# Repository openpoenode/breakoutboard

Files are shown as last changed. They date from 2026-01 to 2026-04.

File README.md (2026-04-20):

# Overview

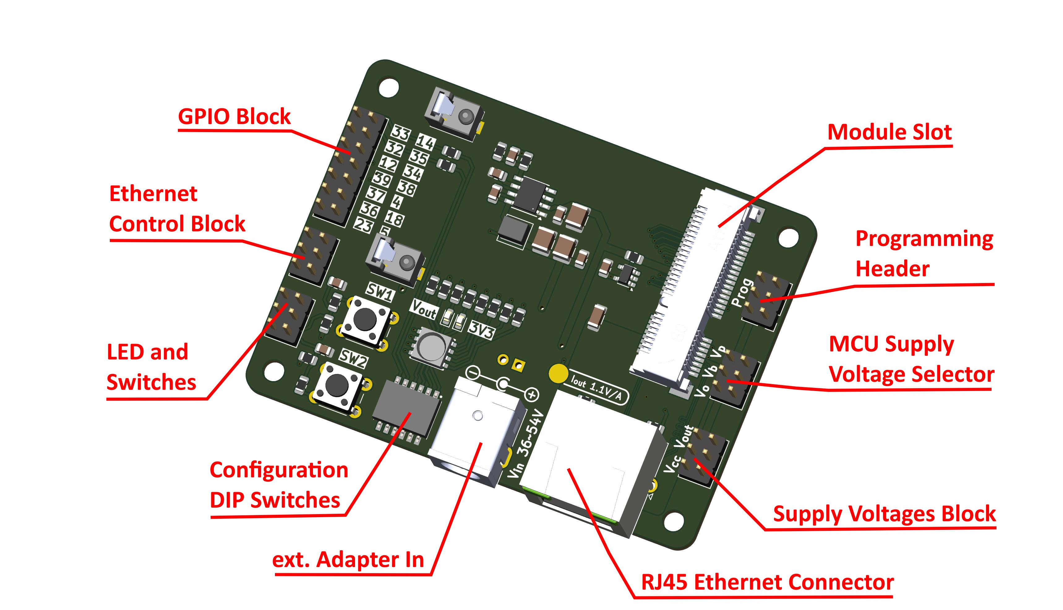
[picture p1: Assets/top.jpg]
BreakoutBoard


The **Breakout Board** carrier is designed to let developers explore the full feature set of the openPoeNode module before committing to a custom carrier design. It includes a range of practical features to simplify testing, evaluation, and firmware debugging.

# Features

The Breakout Board provides a single slot for an openPoeNode module with any supported output voltage. An onboard DC/DC converter is included to step down 5V module output to 3.3V for MCU supply.

## Supply Voltage Selector

The MCU section can be powered from one of three sources:

- Module V<sub>out</sub> directly (for 3.3V modules)
- V<sub>buck</sub> – output of the onboard DC/DC converter (V<sub>out</sub> → 3.3V)
- V<sub>prog</sub> – supplied by an external programmer or debugger

Select the desired source by placing a jumper cap on the corresponding pins.

Although the module includes overvoltage protection, avoid supplying 5V directly to the MCU section.

When powering the board via an external programmer, ensure it can provide sufficient current. Insufficient current may cause unstable behavior during programming (e.g., flash writes failing due to brownouts). If this occurs, use an external power adapter and select V<sub>buck</sub> as the supply source.

## Programming Header

Connector for an external programmer or debugger. The pinout matches the ESP-Prog board from Espressif.

## GPIO Block

All module GPIOs are broken out to this header for general-purpose use. Pin numbering follows the ESP32-D0WD-V3 datasheet.

## Ethernet Control Block

Three GPIOs are required to control the Ethernet interface (**GPIO2 / GPIO13 / GPIO15**). These are routed next to the corresponding **MDC / MDIO / Enable** pins.

- For normal operation, place jumper caps across each row to bridge the signals.
- For testing alternative pin assignments, the signals can be rerouted to other GPIOs using jumper wires.

## LED and Switches

The Breakout Board includes two tactile switches and one RGBW LED for quick testing.

### Switches

- Integrated pull-ups and hardware debouncing
- Output is pulled low when pressed

### LED

- Each channel’s anode is connected to 3.3V via a current-limiting resistor
- Cathodes are exposed on the header and can be driven by open-collector GPIOs

## Configuration DIP Switches

A 6-position DIP switch enables convenient hardware configuration during development:

- **I²C pull-ups (GPIO32 / GPIO33)**
  - 2.2 kΩ pull-ups for easy interfacing with I²C devices
  - Enable with Switch 1 & 2

- **Power load resistors**
  - 100 Ω and 56 Ω resistors from V<sub>out</sub> to GND
  - Useful when very low power consumption causes PoE instability (minimum draw > 0.44 W)
  - Helps prevent PoE power cycling (“hiccup” behavior)
  - Enable individually with Switch 3 & 4

- **Power indicators**
  - LEDs for V<sub>out</sub> and 3.3V rails
  - Enable/disable with Switch 5 & 6 (useful for precise power measurements)

## External Power Adapter

If PoE is unavailable or needs to be overridden, the board can be powered using an external 36–54V DC source.

- Connector: 5.5 × 2.1 mm barrel jack
- Polarity: center positive

## Supply Voltage Block

Provides power outputs for external devices (e.g., sensors):

- V<sub>out</sub> (1x)
- 3.3V (2x)
- Digital GND (3x)

Ensure total consumption remains within the DC/DC converter limits:
- 5V module: up to 1.4A
- 3.3V module: up to 2.1A

## PoE Voltage Block

For advanced use cases, raw PoE input voltage is available for external DC/DC converters.

⚠️ This connector is not populated by default and should be used with caution.

## Supply Current Monitoring

An onboard current monitor IC helps track power consumption and stay within PoE and DC/DC converter limits (0.44W < P < 7W).

- Measures I<sub>out</sub> via a 22 mΩ shunt resistor
- Measure voltage at the test pad (relative to digital ground)
- Current (A) = measured voltage / 1.1

# Physical

- Dimensions: 74 × 55 mm
- PCB: 4-layer FR4, 1.60 mm thickness

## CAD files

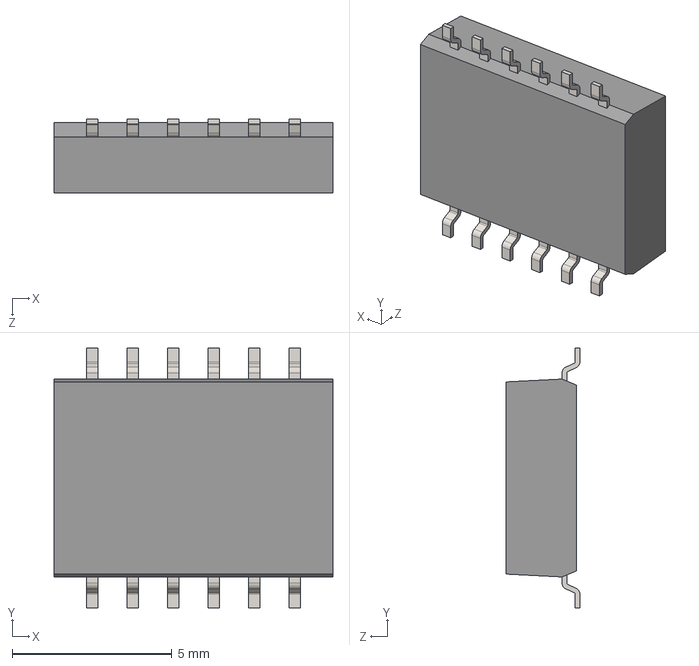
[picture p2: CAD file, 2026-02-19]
3D/GDH06S04.stp
8.74 x 8.13 x 2.31 mm

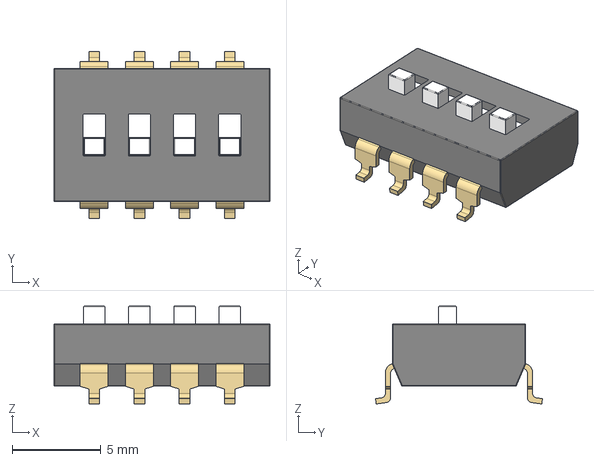
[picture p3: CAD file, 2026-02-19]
3D/ADE04S04.stp
12.1 x 9.38 x 5.50 mm

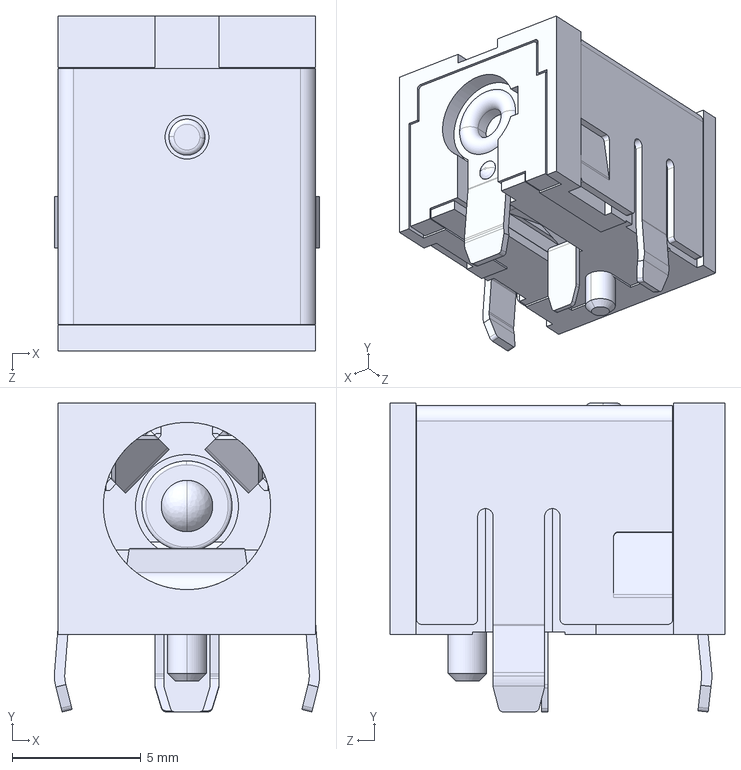
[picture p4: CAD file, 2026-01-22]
3D/PJ-063AH.stp
10.3 x 12.0 x 13.0 mm

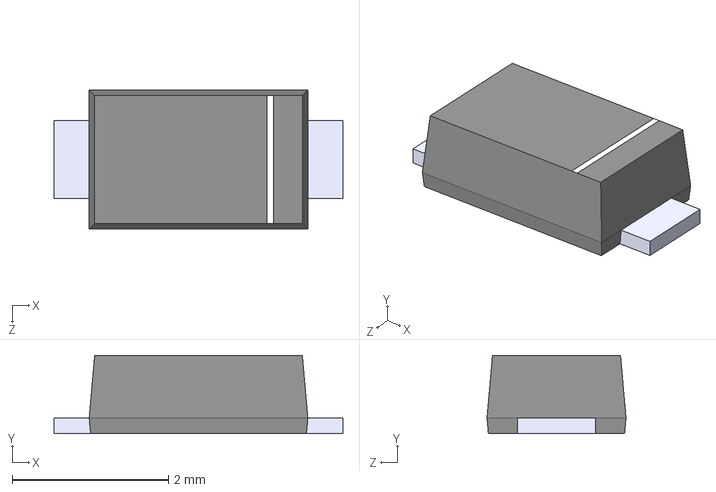
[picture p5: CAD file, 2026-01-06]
3D/AL5809-20P1-7.step
3.70 x 1.00 x 1.78 mm

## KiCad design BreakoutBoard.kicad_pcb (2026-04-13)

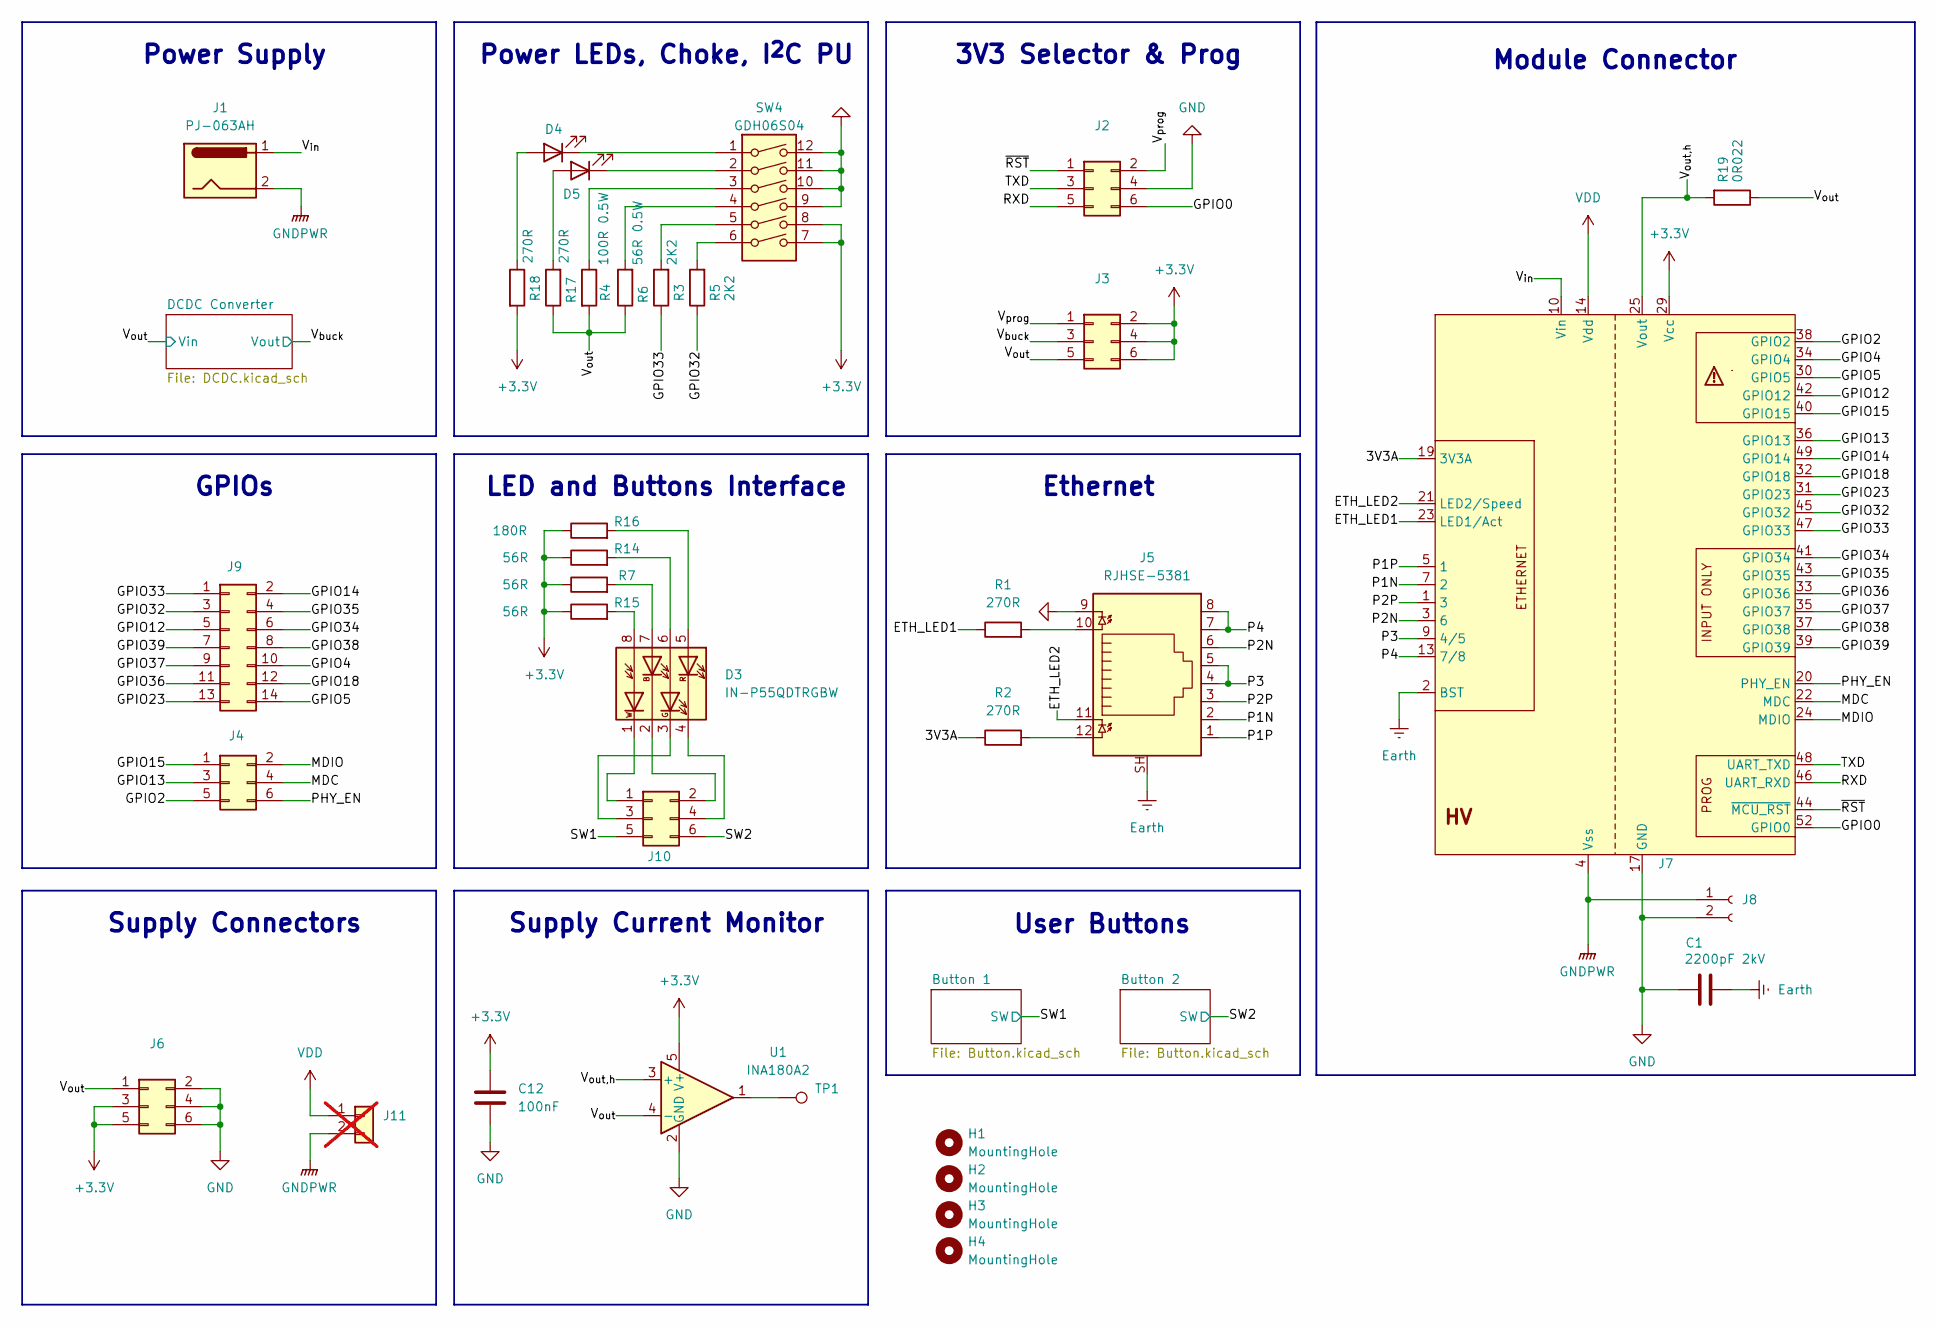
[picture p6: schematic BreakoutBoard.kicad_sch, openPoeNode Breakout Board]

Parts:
C1: 2200pF 2kV; C_1206_3216Metric; MOUSER# 581-1206GC222KAT2A
C12: 100nF; C_0805_2012Metric; MOUSER# 581-KGM21NR71H104KT
D3: IN-P55QDTRGBW; INP55QDTRGBW; MOUSER# 743-IN-P55QDTRGBW
D4, D5: Red; LED_0603_1608Metric; MOUSER# 720-KRELPS122VGVI23H
H1, H2, H3, H4: MountingHole; MountingHole_3.2mm_M3
J1: PJ-063AH; BarrelJack_CUI_PJ-063AH_Horizontal; MOUSER# 490-PJ-063AH
J2, J3, J4, J6, J10: 10129381-906001BLF; PinHeader_2x03_P2.54mm_Vertical; MOUSER# 649-1012938190601BLF
J5: RJHSE-5381; RJ45_Amphenol_RJHSE538X; MOUSER# 523-RJHSE-5381
J7: 119A-80A00-R02
J8: 119A-LATCH-80
J9: 10129381-914001BLF; PinHeader_2x07_P2.54mm_Vertical; MOUSER# 649-1012938191401BLF
J11: PinHeader_1x02_P2.54mm_Vertical; not fitted
R1, R2, R17, R18: 270R; R_0805_2012Metric; MOUSER# 791-WR08X2700FTL
R3, R5: 2K2; R_0805_2012Metric; MOUSER# 791-WR08X222JTL
R4: 100R 0.5W; R_0805_2012Metric; MOUSER# 71-CRCW0805100RFKEAH
R6: 56R 0.5W; R_0805_2012Metric; MOUSER# 660-SG73S2ATTD56R0F
R7, R14, R15: 56R; R_0805_2012Metric; MOUSER# 603-AC0805FR-0756RL
R16: 180R; R_0805_2012Metric; MOUSER# 603-RE0805FRE07180RL
R19: 0R022; R_0805_2012Metric; MOUSER# 667-ERJ-6CWFR022V
SW4: GDH06S04; MOUSER# 506-GDH06S04
TP1: TestPoint; TestPoint_Pad_D3.0mm
U1: INA180A2; SOT-23-5; MOUSER# 595-INA180A2IDBVT

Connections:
+3.3V: C12.2, J3.2, J3.4, J3.6, J6.3, J6.5, J7.29 (Vcc), R7.1, R14.1, R15.1, R16.1, R18.2, SW4.7, SW4.8, U1.5 (V+); also elsewhere on the board
/3V3A: J7.19 (3V3A), R2.1
/ETH_LED1: J7.23 (LED1/Act), R1.1
/ETH_LED2: J5.11, J7.21 (LED2/Speed)
/GPIO0: J2.6, J7.52 (GPIO0)
/GPIO2: J4.5, J7.38 (GPIO2)
/GPIO4: J7.34 (GPIO4), J9.10
/GPIO5: J7.30 (GPIO5), J9.14
/GPIO12: J7.42 (GPIO12), J9.5
/GPIO13: J4.3, J7.36 (GPIO13)
/GPIO14: J7.49 (GPIO14), J9.2
/GPIO15: J4.1, J7.40 (GPIO15)
/GPIO18: J7.32 (GPIO18), J9.12
/GPIO23: J7.31 (GPIO23), J9.13
/GPIO32: J7.45 (GPIO32), J9.3, R5.1
/GPIO33: J7.47 (GPIO33), J9.1, R3.1
/GPIO34: J7.41 (GPIO34), J9.6
/GPIO35: J7.43 (GPIO35), J9.4
/GPIO36: J7.33 (GPIO36), J9.11
/GPIO37: J7.35 (GPIO37), J9.9
/GPIO38: J7.37 (GPIO38), J9.8
/GPIO39: J7.39 (GPIO39), J9.7
/MDC: J4.4, J7.22 (MDC)
/MDIO: J4.2, J7.24 (MDIO)
/P1N: J5.2, J7.7 (2)
/P1P: J5.1, J7.5 (1)
/P2N: J5.6, J7.3 (6)
/P2P: J5.3, J7.1 (3)
/P3: J5.4, J5.5, J7.9 (4/5), J7.11 (4/5)
/P4: J5.7, J5.8, J7.13 (7/8), J7.15 (7/8)
/PHY_EN: J4.6, J7.20 (PHY_EN)
/RXD: J2.5, J7.46 (UART_RXD)
/SW1: J10.5; also elsewhere on the board
/SW2: J10.6; also elsewhere on the board
/TXD: J2.3, J7.48 (UART_TXD)
/V_{buck}: J3.3; also elsewhere on the board
/V_{out,h}: J7.25 (Vout), J7.26 (Vout), J7.27 (Vout), J7.28 (Vout), R19.2, U1.3 (+)
/V_{out}: J3.5, J6.1, R4.2, R6.1, R17.1, R19.1, U1.4 (-); also elsewhere on the board
/V_{prog}: J2.2, J3.1
/~RST: J2.1, J7.44 (~MCU_RST)
Earth: C1.2, J5.SH, J7.2 (BST)
GND: C1.1, C12.1, J2.4, J5.9, J6.2, J6.4, J6.6, J7.17 (GND), J7.18 (GND), J7.50 (GND), J7.51 (GND), J8.2, SW4.9, SW4.10, SW4.11, SW4.12, U1.2 (GND); also elsewhere on the board
GNDPWR: J1.2, J7.4 (Vss), J7.6 (Vss), J7.8 (Vss), J8.1, J11.2
unnamed: D3.7 (AB), R7.2
unnamed: D3.6 (AG), R14.2
unnamed: D3.5 (AR), R16.2
unnamed: D3.8 (AW), R15.2
unnamed: D3.2 (KB), J10.2
unnamed: D3.3 (KG), J10.3
unnamed: D3.4 (KR), J10.4
unnamed: D3.1 (KW), J10.1
unnamed: D4.2 (A), R18.1
unnamed: D4.1 (K), SW4.1
unnamed: D5.2 (A), R17.2
unnamed: D5.1 (K), SW4.2
unnamed: J5.10, R1.2
unnamed: J5.12, R2.2
unnamed: R3.2, SW4.5
unnamed: R4.1, SW4.3
unnamed: R5.2, SW4.6
unnamed: R6.2, SW4.4
unnamed: TP1.1, U1.1
VDD: J7.14 (Vdd), J7.16 (Vdd), J11.1
Vin: J1.1, J7.10 (Vin), J7.12 (Vin)

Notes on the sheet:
GPIOs
Supply Connectors
Module Connector
Power Supply
User Buttons
Supply Current Monitor
Power LEDs, Choke, I^{2}C PU
Ethernet
3V3 Selector & Prog
LED and Buttons Interface

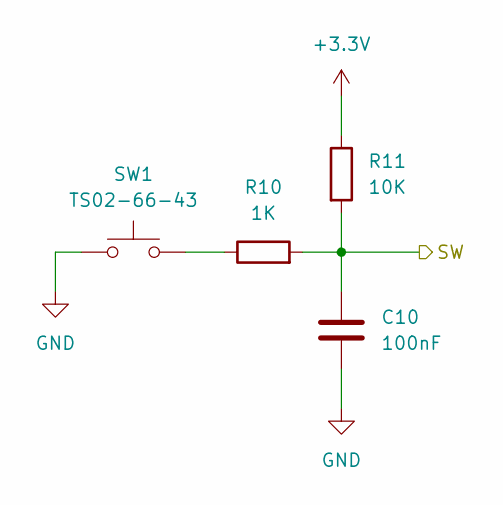
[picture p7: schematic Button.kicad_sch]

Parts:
C10: 100nF; C_0805_2012Metric; MOUSER# 581-KGM21NR71H104KT
R10: 1K; R_0805_2012Metric; MOUSER# 603-RC0805FR-101KL
R11: 10K; R_0805_2012Metric; MOUSER# 603-RC0805FR-7W10KL
SW1: TS02-66-43; SW_PUSH_6mm_H4.3mm; MOUSER# 179-TS026643BK100LCR

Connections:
+3.3V: R11.1; also elsewhere on the board
/SW1: C10.1, R10.2, R11.2; also elsewhere on the board
GND: C10.2, SW1.1; also elsewhere on the board
unnamed: R10.1, SW1.2

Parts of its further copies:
C11: 100nF; C_0805_2012Metric; MOUSER# 581-KGM21NR71H104KT
R12: 1K; R_0805_2012Metric; MOUSER# 603-RC0805FR-101KL
R13: 10K; R_0805_2012Metric; MOUSER# 603-RC0805FR-7W10KL
SW2: TS02-66-43; SW_PUSH_6mm_H4.3mm; MOUSER# 179-TS026643BK100LCR

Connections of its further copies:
+3.3V: R13.1; also elsewhere on the board
/SW2: C11.1, R12.2, R13.2; also elsewhere on the board
GND: C11.2, SW2.1; also elsewhere on the board
unnamed: R12.1, SW2.2

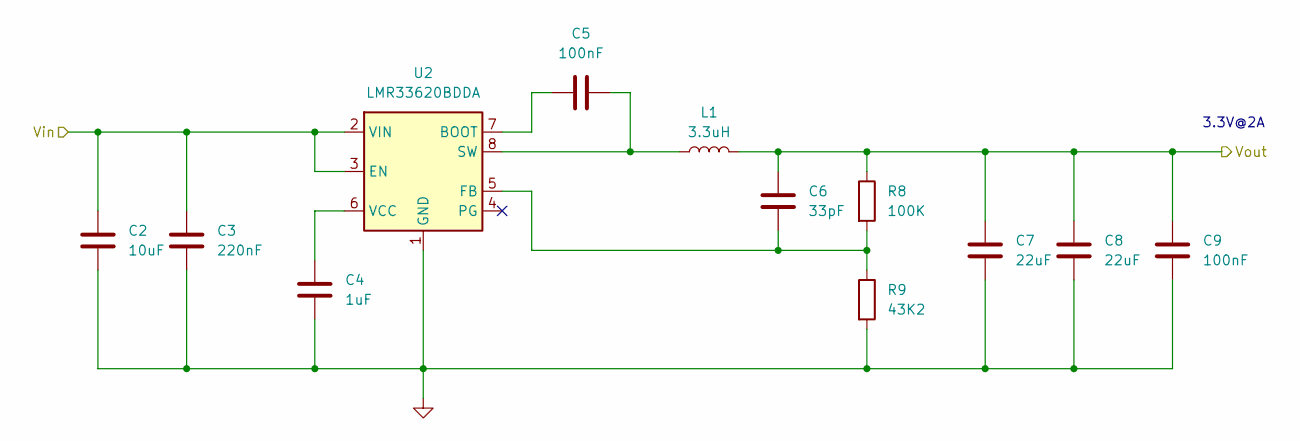
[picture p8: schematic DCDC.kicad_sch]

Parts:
C2: 10uF; C_1210_3225Metric; MOUSER# 810-C3225X7R1H106250
C3: 220nF; C_0805_2012Metric; MOUSER# 810-C2012X7R1H224K
C4: 1uF; C_0805_2012Metric; MOUSER# 187-CL21B105KAFNNNE
C5, C9: 100nF; C_0805_2012Metric; MOUSER# 581-KGM21NR71H104KT
C6: 33pF; C_0805_2012Metric; MOUSER# 80-C0805C330J5GACLR
C7, C8: 22uF; C_1210_3225Metric; MOUSER# 187-CL32B226KOJNNNE
L1: 3.3uH; L_Wuerth_MAPI-4030; MOUSER# 710-74438357033
R8: 100K; R_0805_2012Metric; MOUSER# 603-RE0805FRE07100KL
R9: 43K2; R_0805_2012Metric; MOUSER# 603-RC0805FR-0743K2L
U2: LMR33620BDDA; Texas_HSOP-8-1EP_3.9x4.9mm_P1.27mm_ThermalVias; MOUSER# 595-LMR33620BDDAR

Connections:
/V_{buck}: C6.1, C7.1, C8.1, C9.1, L1.2, R8.1; also elsewhere on the board
/V_{out}: C2.1, C3.1, U2.2 (VIN), U2.3 (EN); also elsewhere on the board
GND: C2.2, C3.2, C4.2, C7.2, C8.2, C9.2, R9.2, U2.1 (GND), U2.9 (GND); also elsewhere on the board
unnamed: C5.1, U2.7 (BOOT)
unnamed: C6.2, R8.2, R9.1, U2.5 (FB)
unnamed: C5.2, L1.1, U2.8 (SW)
unnamed: C4.1, U2.6 (VCC)

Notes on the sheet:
3.3V@2A

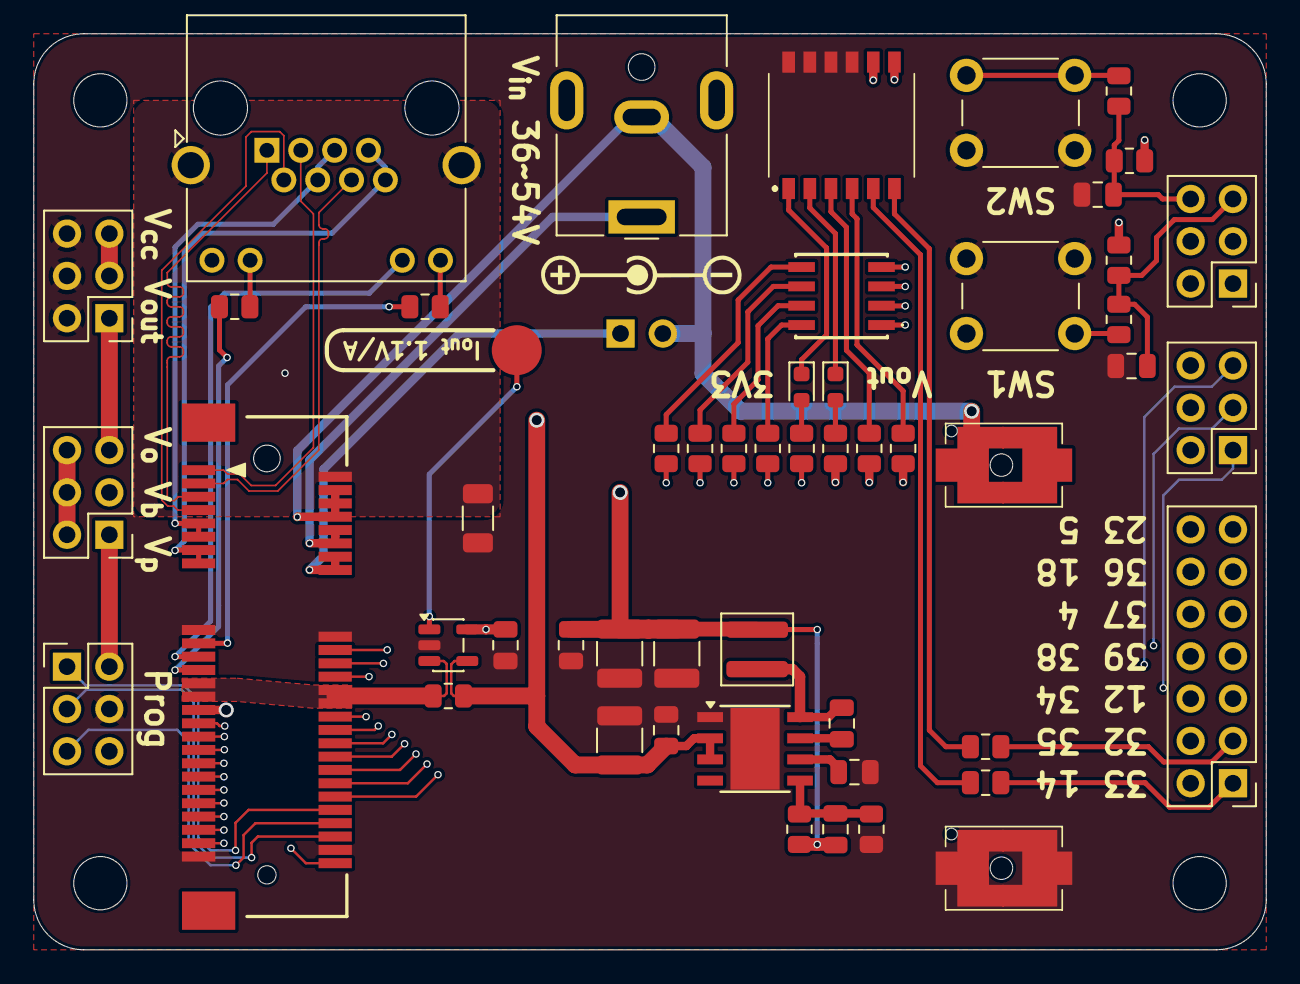
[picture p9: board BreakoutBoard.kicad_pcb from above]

Board: 4 copper layers, 74.0 x 55.0 mm, 56 parts (0 on the bottom side), 70 nets.

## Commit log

2026-01-22 updated DC jack 3D model moved reference designators on PCB added LED datasheet
    [BreakoutBoard.kicad_pcb, BreakoutBoard.kicad_sch, PJ-063AH.stp]
2026-01-23 fixed wrong part number for tactile switches (leg length short -> long)
    [Button.kicad_sch]
2026-02-15 updated RJ45 connector part number and fixed silk screen mistakes on GPIO numbering
    [BreakoutBoard.kicad_pcb, BreakoutBoard.kicad_sch]
2026-02-16 fixed RJ45 connector type value
    [BreakoutBoard.kicad_sch]
2026-02-17 added revision silkscreen text
    [BreakoutBoard.kicad_pcb]
2026-02-19 completed routing for revision 0.2
    [ADE04S04.stp, BreakoutBoard.kicad_pcb, BreakoutBoard.kicad_sch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]
2026-02-20 completed silk screen
    [BreakoutBoard.kicad_pcb, BreakoutBoard.kicad_sch, DCDC.kicad_sch]
2026-03-19 minor changes
    [BreakoutBoard.kicad_pcb]
2026-03-19 added IDAnything
    [BreakoutBoard.kicad_sch, Button.kicad_sch, DCDC.kicad_sch]
2026-04-09 arranged reference designators
    [BreakoutBoard.kicad_pcb, BreakoutBoard.kicad_sch]
2026-04-13 added external adapter voltage and polarity clarification on silk screen
    [BreakoutBoard.kicad_pcb]
2026-04-22 removed comment
    [Button.kicad_sch, DCDC.kicad_sch]

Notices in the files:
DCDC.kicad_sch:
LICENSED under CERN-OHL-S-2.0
